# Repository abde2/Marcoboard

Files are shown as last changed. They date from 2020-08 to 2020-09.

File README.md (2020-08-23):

# Marcoboard
 This is going to be my first deep delve into keyboard design. I am going to be creating most of this myself using ai03 PCB design guides and other guides that will help me along the way. This would be much simpler if I could use a pro micro and socket it onto the board but I need a total of 27 usable pins, along with it being a DIP package as I suck at soldering surface mount chips.
 The keyboard itself will be a 65% keyboard that will utilise 2 rotary encoders, with push switches, along with an OLED screen inbetween them so that you can easily tell which layer you are on. 
 RGB lighting may also be included if I can figure it out but it isn't exactly necessary. I may only create a capslock light for it.
 This is going to be useful for flashing the bootloader onto it. https://www.instructables.com/id/Burning-Arduino-Bootloader-to-Atmega-32A-PU-Using-/
 http://vusb.wikidot.com/hardware
 https://www.reddit.com/r/MechanicalKeyboards/comments/5xubd7/adding_oled_display_to_your_build_using_qmk/

 Current Progress:
 The first revision of the development board is finished. This is so that I can hand solder the components because I won't be able to manage QFN packages. 
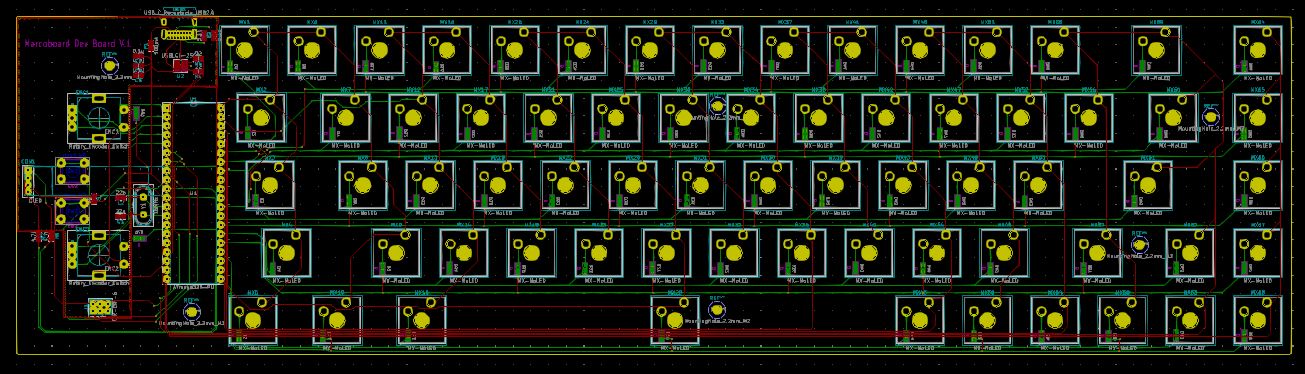
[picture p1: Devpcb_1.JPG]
 
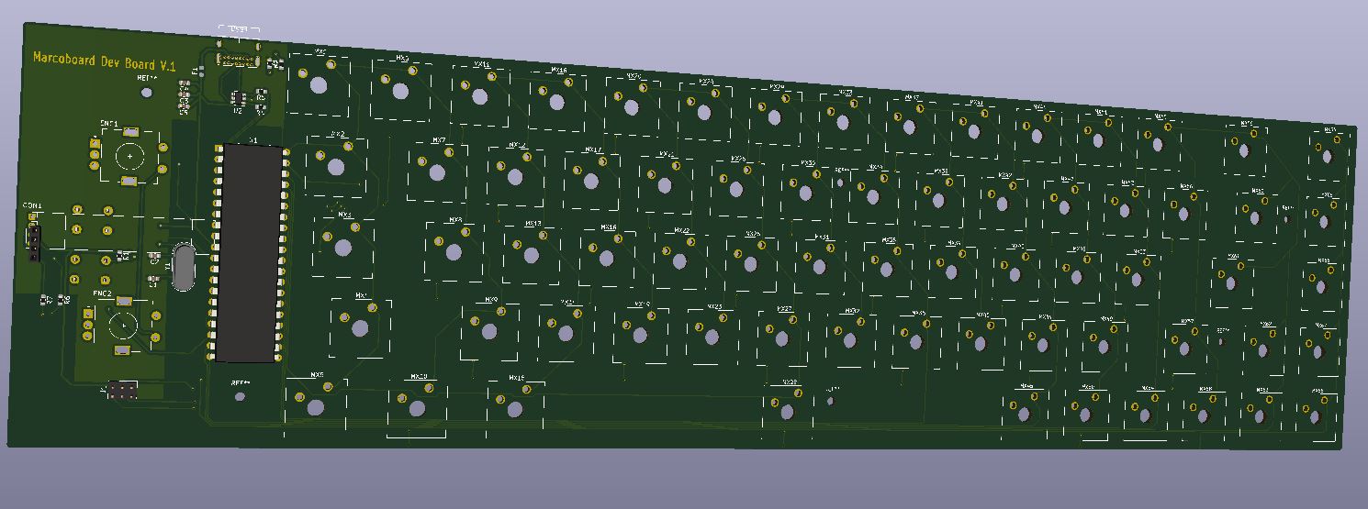
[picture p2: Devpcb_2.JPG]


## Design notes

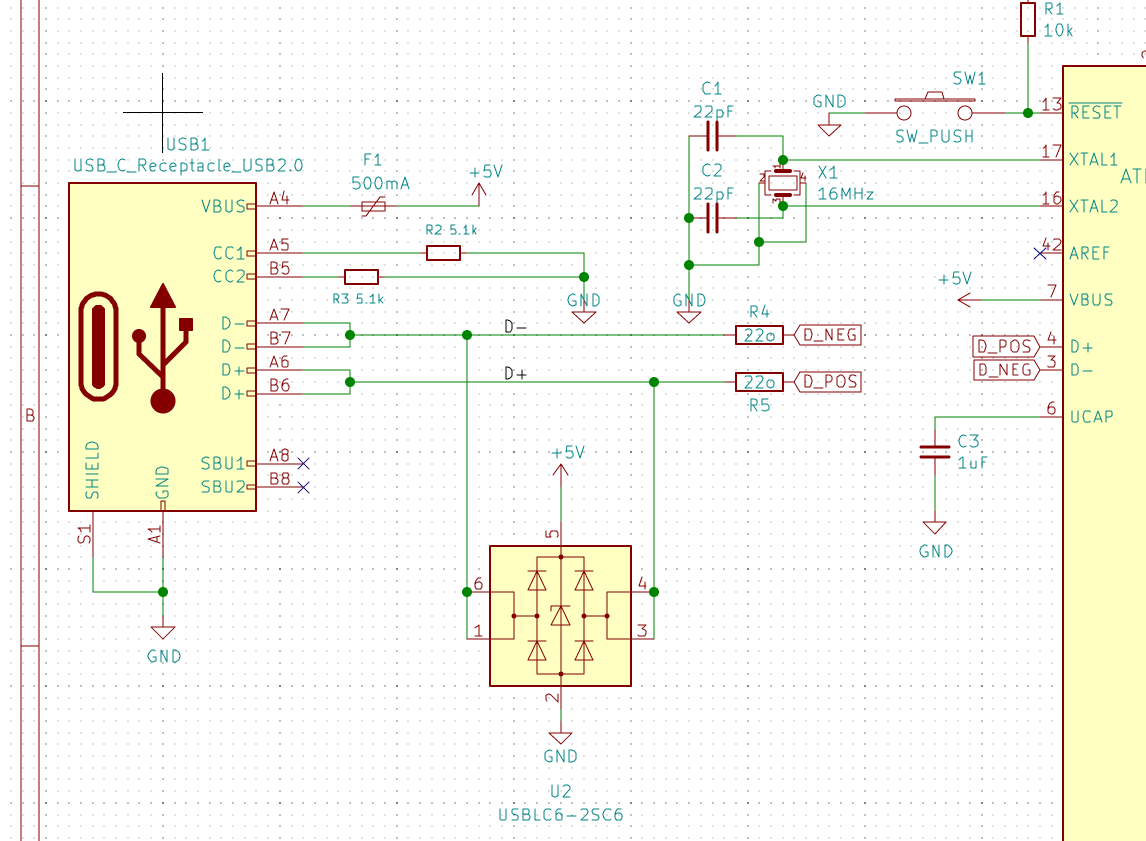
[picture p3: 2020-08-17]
USBC.png

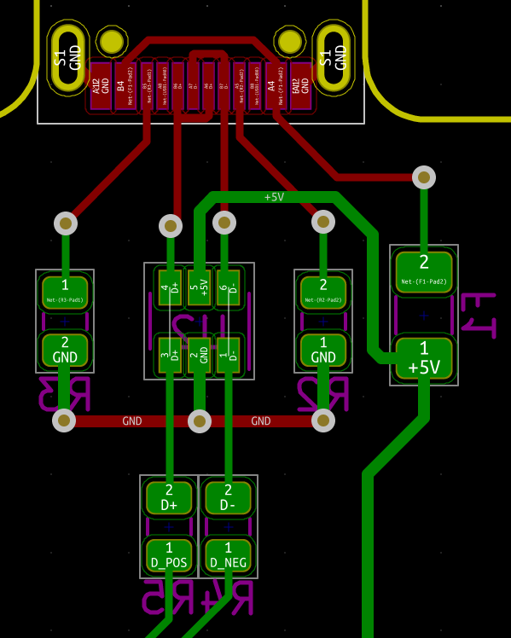
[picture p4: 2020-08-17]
USBC PCB.png

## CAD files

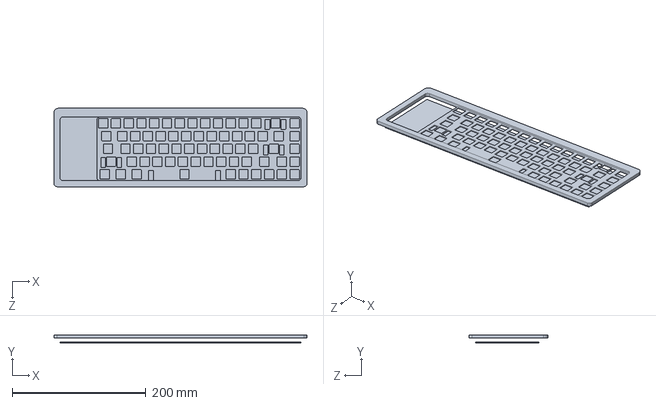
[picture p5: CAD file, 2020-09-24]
Case files/Case Bottom.SLDPRT
377.6 x 12.6 x 117.2 mm

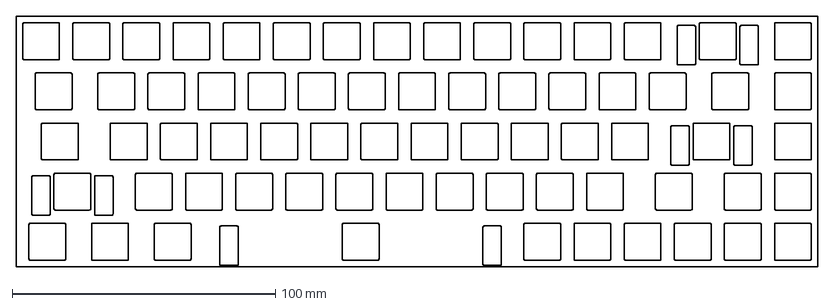
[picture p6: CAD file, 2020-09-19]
Case files/plate.dxf
304.8 x 95.2 mm

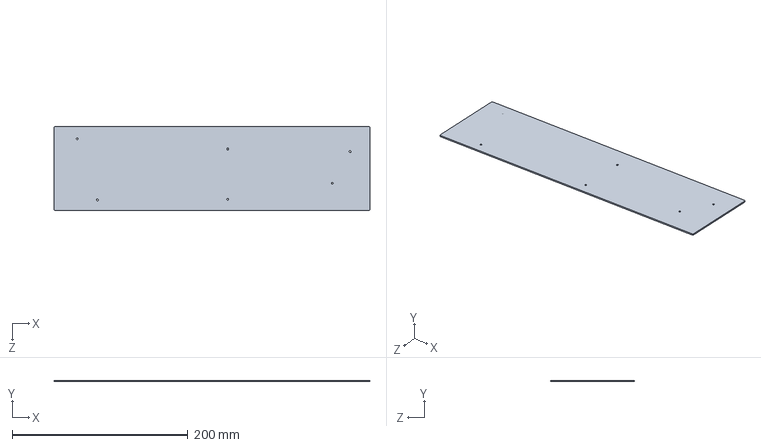
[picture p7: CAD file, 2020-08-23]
Case files/PCB.SLDPRT
359.6 x 1.60 x 95.2 mm

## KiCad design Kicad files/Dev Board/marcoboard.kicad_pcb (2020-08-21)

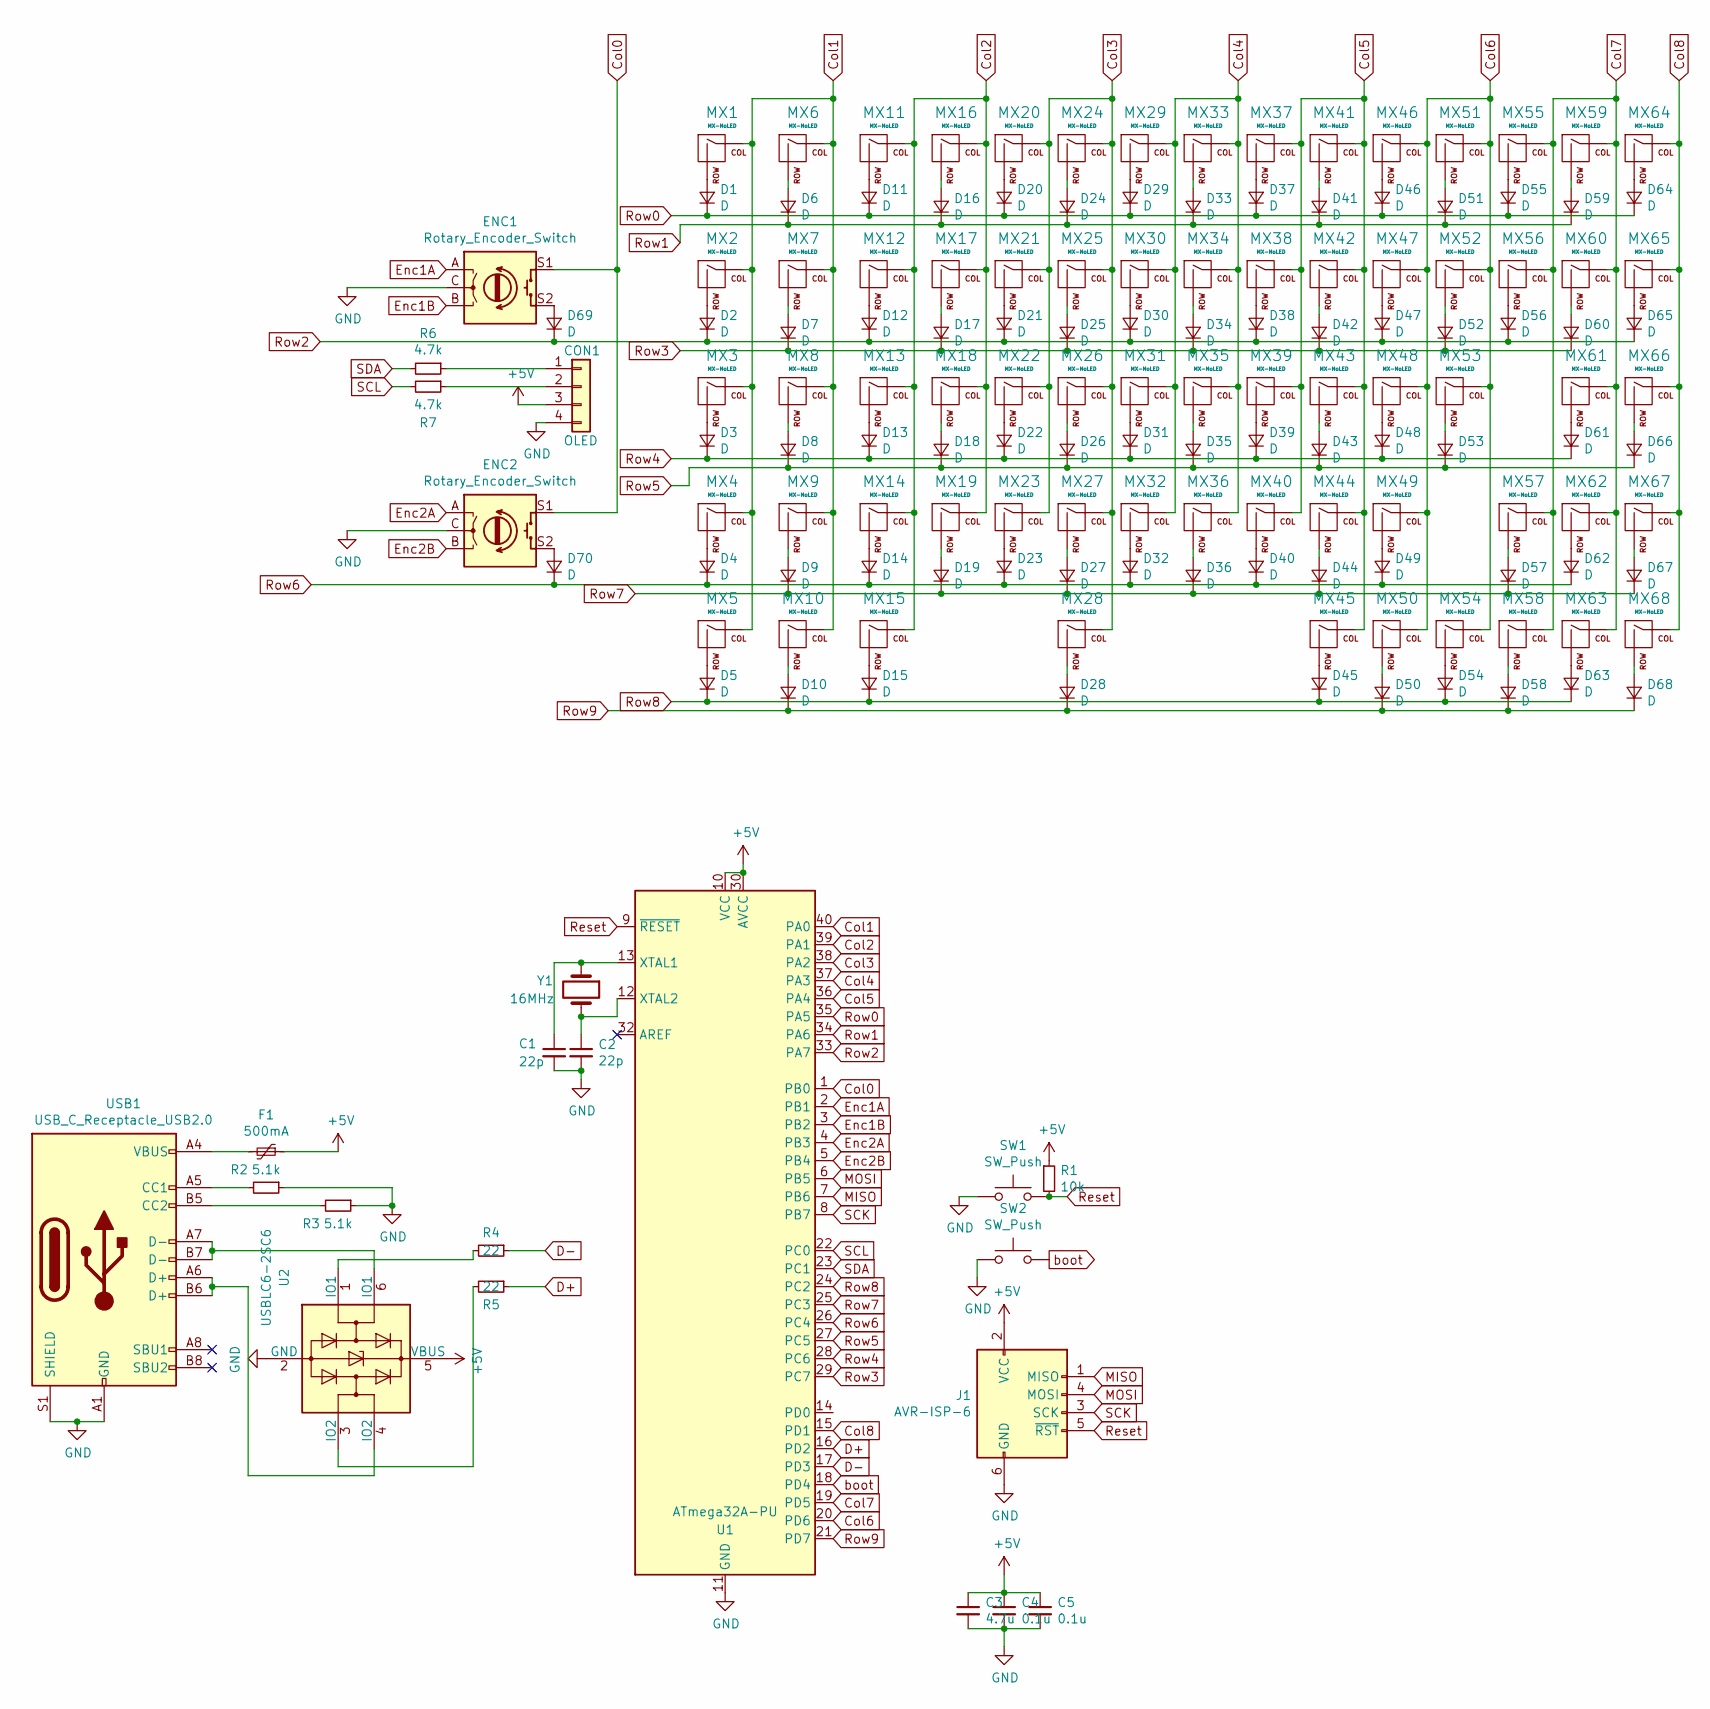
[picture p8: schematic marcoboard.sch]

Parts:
C1, C2: 22p; C_0603_1608Metric
C3: 4.7u; C_0603_1608Metric
C4, C5: 0.1u; C_0603_1608Metric
CON1: OLED; 128x32OLED
D1, D2, D3, D4, D5, D6, D7, D8, D9, D10, D11, D12, D13, D14, D15, D16, D17, D18, D19, D20, D21, D22, D23, D24, D25, D26, D27, D28, D29, D30, D31, D32, D33, D34, D35, D36, D37, D38, D39, D40, D41, D42, D43, D44, D45, D46, D47, D48, D49, D50, D51, D52, D53, D54, D55, D56, D57, D58, D59, D60, D61, D62, D63, D64, D65, D66, D67, D68, D69, D70: D; D_SC79
ENC1, ENC2: Rotary_Encoder_Switch; RotaryEncoder_Alps_EC11E-Switch_Vertical_H20mm
F1: 500mA; Fuse_0603_1608Metric
J1: AVR-ISP-6; PinHeader_2x03_P2.00mm_Vertical
MX1, MX6, MX7, MX8, MX9, MX11, MX12, MX13, MX14, MX16, MX17, MX18, MX19, MX20, MX21, MX22, MX23, MX24, MX25, MX26, MX27, MX29, MX30, MX31, MX32, MX33, MX34, MX35, MX36, MX37, MX38, MX39, MX40, MX41, MX42, MX43, MX44, MX45, MX46, MX47, MX48, MX49, MX50, MX51, MX52, MX53, MX54, MX55, MX56, MX58, MX62, MX63, MX64, MX65, MX66, MX67, MX68: MX-NoLED; SW_Cherry_MX_1.00u_Plate
MX2, MX60: MX-NoLED; SW_Cherry_MX_1.50u_Plate
MX3, MX57: MX-NoLED; SW_Cherry_MX_1.75u_Plate
MX4, MX61: MX-NoLED; SW_Cherry_MX_2.25u_Plate
MX5, MX10, MX15: MX-NoLED; SW_Cherry_MX_1.25u_Plate
MX28: MX-NoLED; SW_Cherry_MX_6.25u_Plate
MX59: MX-NoLED; SW_Cherry_MX_2.00u_Plate
R1: 10k; R_0603_1608Metric
R2, R3: 5.1k; R_0603_1608Metric
R4, R5: 22; R_0603_1608Metric
R6, R7: 4.7k; R_0603_1608Metric
SW1, SW2: SW_Push; SW_PUSH_6mm
U1: ATmega32A-PU; DIP-40_W15.24mm
U2: USBLC6-2SC6; SOT-23-6
USB1: USB_C_Receptacle_USB2.0; USB_C_GCT_USB4085
Y1: 16MHz; Crystal_HC49-U_Vertical

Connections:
+5V: C3.1, C4.1, C5.1, CON1.3, F1.1, J1.2 (VCC), R1.1, U1.10 (VCC), U1.30 (AVCC), U2.5 (VBUS)
Col0: ENC1.S1, ENC2.S1, U1.1 (PB0)
Col1: MX1.1 (COL), MX2.1 (COL), MX3.1 (COL), MX4.1 (COL), MX5.1 (COL), MX6.1 (COL), MX7.1 (COL), MX8.1 (COL), MX9.1 (COL), MX10.1 (COL), U1.40 (PA0)
Col2: MX11.1 (COL), MX12.1 (COL), MX13.1 (COL), MX14.1 (COL), MX15.1 (COL), MX16.1 (COL), MX17.1 (COL), MX18.1 (COL), MX19.1 (COL), U1.39 (PA1)
Col3: MX20.1 (COL), MX21.1 (COL), MX22.1 (COL), MX23.1 (COL), MX24.1 (COL), MX25.1 (COL), MX26.1 (COL), MX27.1 (COL), MX28.1 (COL), U1.38 (PA2)
Col4: MX29.1 (COL), MX30.1 (COL), MX31.1 (COL), MX32.1 (COL), MX33.1 (COL), MX34.1 (COL), MX35.1 (COL), MX36.1 (COL), U1.37 (PA3)
Col5: MX37.1 (COL), MX38.1 (COL), MX39.1 (COL), MX40.1 (COL), MX41.1 (COL), MX42.1 (COL), MX43.1 (COL), MX44.1 (COL), MX45.1 (COL), U1.36 (PA4)
Col6: MX46.1 (COL), MX47.1 (COL), MX48.1 (COL), MX49.1 (COL), MX50.1 (COL), MX51.1 (COL), MX52.1 (COL), MX53.1 (COL), MX54.1 (COL), U1.20 (PD6)
Col7: MX55.1 (COL), MX56.1 (COL), MX57.1 (COL), MX58.1 (COL), MX59.1 (COL), MX60.1 (COL), MX61.1 (COL), MX62.1 (COL), MX63.1 (COL), U1.19 (PD5)
Col8: MX64.1 (COL), MX65.1 (COL), MX66.1 (COL), MX67.1 (COL), MX68.1 (COL), U1.15 (PD1)
D+: R5.1, U1.16 (PD2)
D-: R4.1, U1.17 (PD3)
Enc1A: ENC1.A, U1.2 (PB1)
Enc1B: ENC1.B, U1.3 (PB2)
Enc2A: ENC2.A, U1.4 (PB3)
Enc2B: ENC2.B, U1.5 (PB4)
GND: C1.2, C2.2, C3.2, C4.2, C5.2, CON1.4, ENC1.C, ENC2.C, J1.6 (GND), R2.1, R3.1, SW1.1, SW2.1, U1.11 (GND), U1.31 (GND), U2.2 (GND), USB1.A1 (GND), USB1.A12 (GND), USB1.B1 (GND), USB1.B12 (GND), USB1.S1 (SHIELD)
MISO: J1.1 (MISO), U1.7 (PB6)
MOSI: J1.4 (MOSI), U1.6 (PB5)
unnamed: C1.1, U1.13 (XTAL1), Y1.1
unnamed: C2.1, U1.12 (XTAL2), Y1.2
unnamed: CON1.1, R6.1
unnamed: CON1.2, R7.1
unnamed: D1.2 (A), MX1.2 (ROW)
unnamed: D2.2 (A), MX2.2 (ROW)
unnamed: D3.2 (A), MX3.2 (ROW)
unnamed: D4.2 (A), MX4.2 (ROW)
unnamed: D5.2 (A), MX5.2 (ROW)
unnamed: D6.2 (A), MX6.2 (ROW)
unnamed: D7.2 (A), MX7.2 (ROW)
unnamed: D8.2 (A), MX8.2 (ROW)
unnamed: D9.2 (A), MX9.2 (ROW)
unnamed: D10.2 (A), MX10.2 (ROW)
unnamed: D11.2 (A), MX11.2 (ROW)
unnamed: D12.2 (A), MX12.2 (ROW)
unnamed: D13.2 (A), MX13.2 (ROW)
unnamed: D14.2 (A), MX14.2 (ROW)
unnamed: D15.2 (A), MX15.2 (ROW)
unnamed: D16.2 (A), MX16.2 (ROW)
unnamed: D17.2 (A), MX17.2 (ROW)
unnamed: D18.2 (A), MX18.2 (ROW)
unnamed: D19.2 (A), MX19.2 (ROW)
unnamed: D20.2 (A), MX20.2 (ROW)
unnamed: D21.2 (A), MX21.2 (ROW)
unnamed: D22.2 (A), MX22.2 (ROW)
unnamed: D23.2 (A), MX23.2 (ROW)
unnamed: D24.2 (A), MX24.2 (ROW)
unnamed: D25.2 (A), MX25.2 (ROW)
unnamed: D26.2 (A), MX26.2 (ROW)
unnamed: D27.2 (A), MX27.2 (ROW)
unnamed: D28.2 (A), MX28.2 (ROW)
unnamed: D29.2 (A), MX29.2 (ROW)
unnamed: D30.2 (A), MX30.2 (ROW)
unnamed: D31.2 (A), MX31.2 (ROW)
unnamed: D32.2 (A), MX32.2 (ROW)
unnamed: D33.2 (A), MX33.2 (ROW)
unnamed: D34.2 (A), MX34.2 (ROW)
unnamed: D35.2 (A), MX35.2 (ROW)
unnamed: D36.2 (A), MX36.2 (ROW)
unnamed: D37.2 (A), MX37.2 (ROW)
unnamed: D38.2 (A), MX38.2 (ROW)
unnamed: D39.2 (A), MX39.2 (ROW)
unnamed: D40.2 (A), MX40.2 (ROW)
unnamed: D41.2 (A), MX41.2 (ROW)
unnamed: D42.2 (A), MX42.2 (ROW)
unnamed: D43.2 (A), MX43.2 (ROW)
unnamed: D44.2 (A), MX44.2 (ROW)
unnamed: D45.2 (A), MX45.2 (ROW)
unnamed: D46.2 (A), MX46.2 (ROW)
unnamed: D47.2 (A), MX47.2 (ROW)
unnamed: D48.2 (A), MX48.2 (ROW)
unnamed: D49.2 (A), MX49.2 (ROW)
unnamed: D50.2 (A), MX50.2 (ROW)
unnamed: D51.2 (A), MX51.2 (ROW)
unnamed: D52.2 (A), MX52.2 (ROW)
unnamed: D53.2 (A), MX53.2 (ROW)
unnamed: D54.2 (A), MX54.2 (ROW)
unnamed: D55.2 (A), MX55.2 (ROW)
unnamed: D56.2 (A), MX56.2 (ROW)
unnamed: D57.2 (A), MX57.2 (ROW)
unnamed: D58.2 (A), MX58.2 (ROW)
unnamed: D59.2 (A), MX59.2 (ROW)
unnamed: D60.2 (A), MX60.2 (ROW)
unnamed: D61.2 (A), MX61.2 (ROW)
unnamed: D62.2 (A), MX62.2 (ROW)
unnamed: D63.2 (A), MX63.2 (ROW)
unnamed: D64.2 (A), MX64.2 (ROW)
unnamed: D65.2 (A), MX65.2 (ROW)
unnamed: D66.2 (A), MX66.2 (ROW)
unnamed: D67.2 (A), MX67.2 (ROW)
unnamed: D68.2 (A), MX68.2 (ROW)
unnamed: D69.2 (A), ENC1.S2
unnamed: D70.2 (A), ENC2.S2
unnamed: F1.2, USB1.A4 (VBUS), USB1.A9 (VBUS), USB1.B4 (VBUS), USB1.B9 (VBUS)
unnamed: R2.2, USB1.A5 (CC1)
unnamed: R3.2, USB1.B5 (CC2)
unnamed: R4.2, U2.1 (IO1)
unnamed: R5.2, U2.3 (IO2)
unnamed: U2.4 (IO2), USB1.A6 (D+), USB1.B6 (D+)
unnamed: U2.6 (IO1), USB1.A7 (D-), USB1.B7 (D-)
Reset: J1.5 (~RST), R1.2, SW1.2, U1.9 (~RESET)
Row0: D1.1 (K), D11.1 (K), D20.1 (K), D29.1 (K), D37.1 (K), D46.1 (K), D55.1 (K), D64.1 (K), U1.35 (PA5)
Row1: D6.1 (K), D16.1 (K), D24.1 (K), D33.1 (K), D41.1 (K), D51.1 (K), D59.1 (K), U1.34 (PA6)
Row2: D2.1 (K), D12.1 (K), D21.1 (K), D30.1 (K), D38.1 (K), D47.1 (K), D56.1 (K), D65.1 (K), D69.1 (K), U1.33 (PA7)
Row3: D7.1 (K), D17.1 (K), D25.1 (K), D34.1 (K), D42.1 (K), D52.1 (K), D60.1 (K), U1.29 (PC7)
Row4: D3.1 (K), D13.1 (K), D22.1 (K), D31.1 (K), D39.1 (K), D48.1 (K), D61.1 (K), U1.28 (PC6)
Row5: D8.1 (K), D18.1 (K), D26.1 (K), D35.1 (K), D43.1 (K), D53.1 (K), D66.1 (K), U1.27 (PC5)
Row6: D4.1 (K), D14.1 (K), D23.1 (K), D32.1 (K), D40.1 (K), D49.1 (K), D62.1 (K), D70.1 (K), U1.26 (PC4)
Row7: D9.1 (K), D19.1 (K), D27.1 (K), D36.1 (K), D44.1 (K), D57.1 (K), D67.1 (K), U1.25 (PC3)
Row8: D5.1 (K), D15.1 (K), D45.1 (K), D54.1 (K), D63.1 (K), U1.24 (PC2)
Row9: D10.1 (K), D28.1 (K), D50.1 (K), D58.1 (K), D68.1 (K), U1.21 (PD7)
SCK: J1.3 (SCK), U1.8 (PB7)
SCL: R7.2, U1.22 (PC0)
SDA: R6.2, U1.23 (PC1)
boot: SW2.2, U1.18 (PD4)

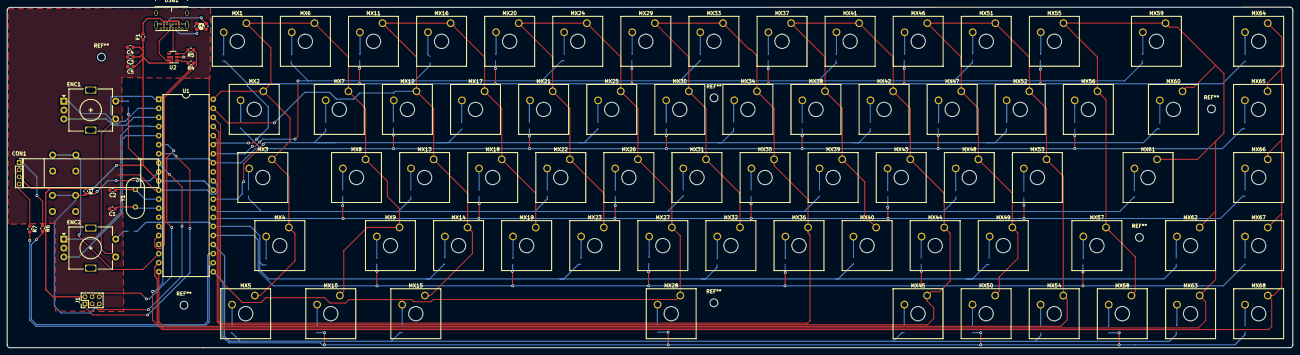
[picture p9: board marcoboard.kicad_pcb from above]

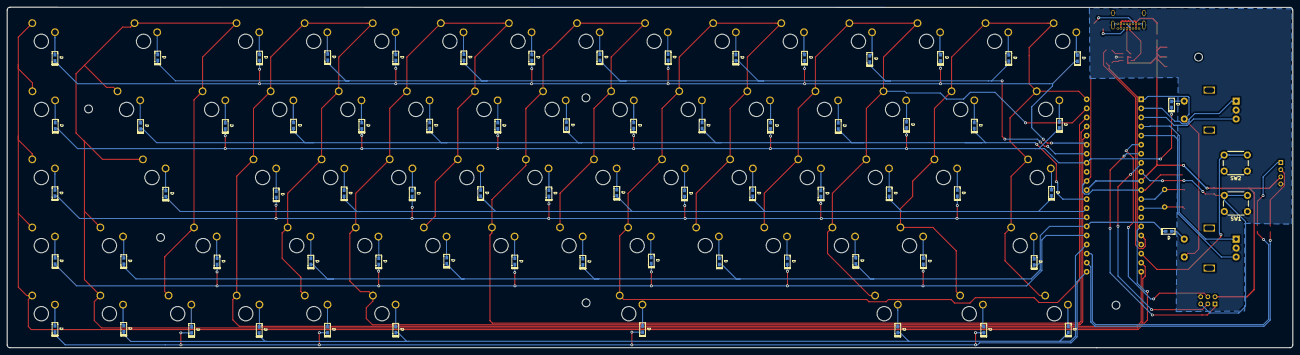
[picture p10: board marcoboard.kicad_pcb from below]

Board: 2 copper layers, 359.7 x 95.2 mm, 161 parts (72 on the bottom side), 115 nets.

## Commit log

2020-08-17 Create Kicad_files
2020-08-17 Add submodules
    [_saved_marcoboard.sch]
2020-08-18 Removed OLED
    [_saved_marcoboard.sch, marcoboard.sch]
2020-08-18 Board updates
    [marcoboard.sch]
2020-08-19 Dev board difference added
    [marcoboard.kicad_pcb, marcoboard.sch]
2020-08-21 PCB finished
    [marcoboard-B_Cu.gbr, marcoboard-B_Mask.gbr, marcoboard-B_Paste.gbr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]
2020-08-21 Finished dev pcb
    [marcoboard-B_Cu.gbr, marcoboard-B_Mask.gbr, marcoboard-B_Paste.gbr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]
2020-08-23 Case design
    [Case Bottom.SLDPRT, PCB.SLDPRT]
2020-09-08 Update Case Bottom.SLDPRT
    [Case Bottom.SLDPRT]
2020-09-14 Case files
    [Case Bottom.SLDPRT]
2020-09-21 more and more and more and more and more and more case stuff
    [Case Bottom.SLDPRT]
2020-09-24 more stuff
    [Case Bottom.SLDPRT]
2020-09-24 more shtuff
    [Case Bottom.SLDPRT]
